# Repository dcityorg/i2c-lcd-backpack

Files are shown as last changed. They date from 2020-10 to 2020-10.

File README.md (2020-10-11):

#### I²C LCD Backpack Board for character LCD modules

<div style="text-align: center;">
<div style="display: inline-block; margin-right: 5px;">
<a href="https://www.dcity.org/dcity/wp-content/uploads/i2c-lcd-with-blackboard.jpg"><img src="https://www.dcity.org/dcity/wp-content/uploads/i2c-lcd-with-blackboard-600x400.jpg" alt="" width="300" height=“200" class="alignnone size-medium wp-image-517" /></a>
</div>
<div style="display: inline-block; margin-right: 5px;">

</div>
<div style="display: inline-block; margin-right: 5px;">
<a href="https://www.dcity.org/dcity/wp-content/uploads/i2c-lcd.jpg"><img src="https://www.dcity.org/dcity/wp-content/uploads/i2c-lcd-600x400.jpg" alt="" width="300" height=“200" class="alignnone size-medium wp-image-517" /></a>
</div>
</div>

**[This link has details](https://www.dcity.org/portfolio/i2c-lcd-backpack-board/) including**
* parts lists
* assembly instructions
* jumper configuration
* Arduino, Particle and Raspberry Pi software library usage
* Bare PC boards are available from OSHPark.

**License Information**
Open Source Hardware Design. Our License Information is [here](https://www.dcity.org/license-information/).

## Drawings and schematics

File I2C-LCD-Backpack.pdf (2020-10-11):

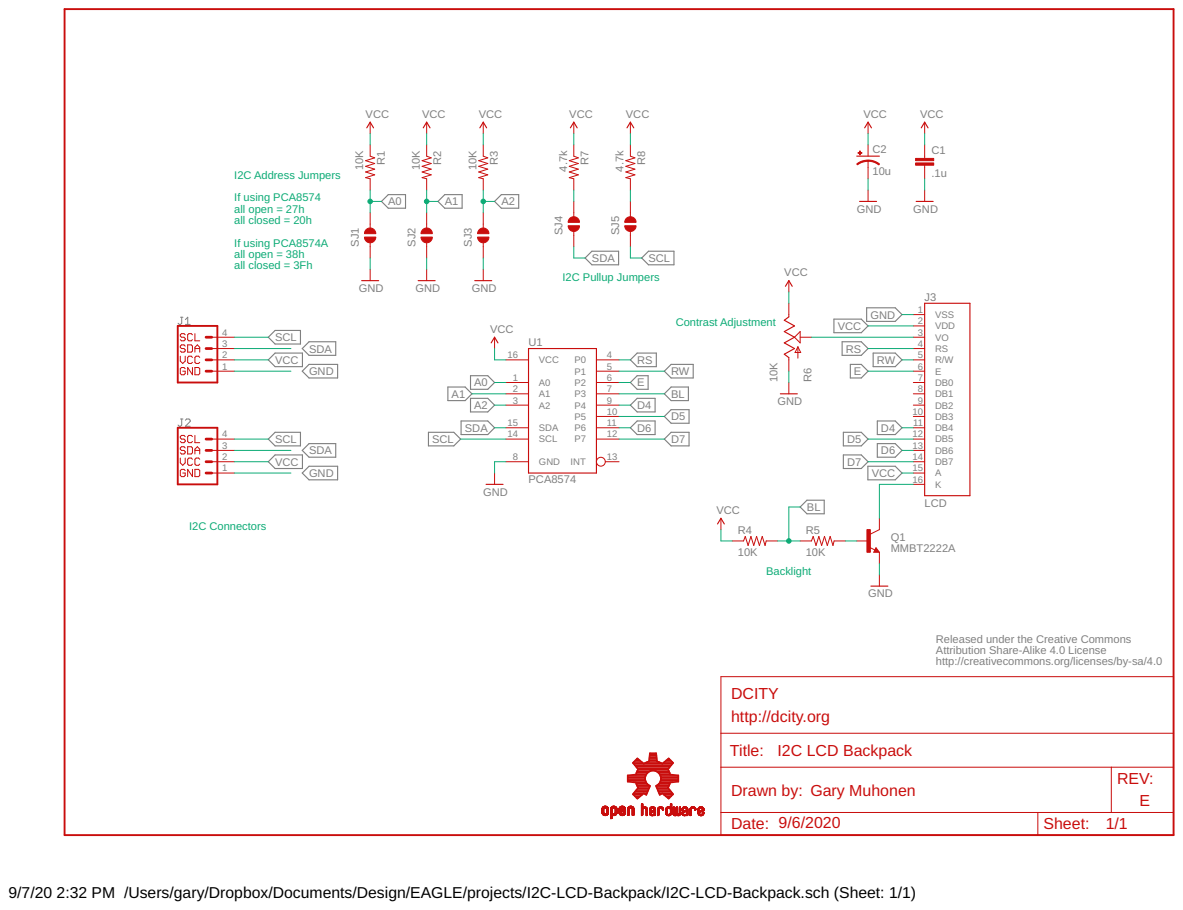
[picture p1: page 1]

I2C Address Jumpers
If using PCA8574
all open = 27h
all closed = 20h
If using PCA8574A
all open = 38h
I2C Pullup Jumpers all closed = 3Fh

Released under the Creative Commons http://creativecommons.org/licenses/by-sa/4.0
Attribution Share-Alike 4.0 License

Drawn by: | REV: E Gary Muhonen

Date: 9/6/2020 | Sheet: 1/1

9/7/20 2:32 PM /Users/gary/Dropbox/Documents/Design/EAGLE/projects/I2C-LCD-Backpack/I2C-LCD-Backpack.sch (Sheet: 1/1)

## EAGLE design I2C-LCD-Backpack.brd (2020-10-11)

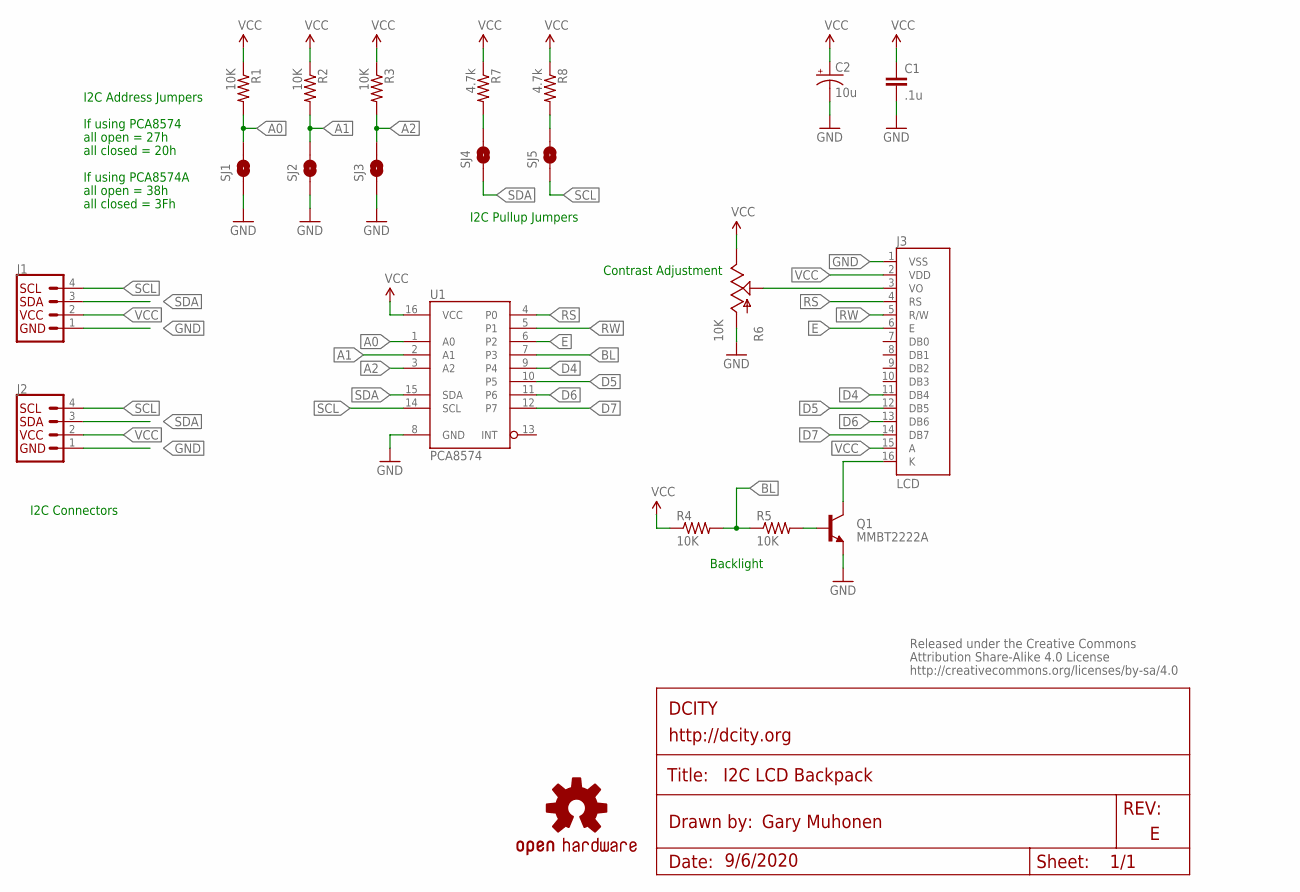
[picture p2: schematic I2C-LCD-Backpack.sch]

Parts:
C1: .1u; 0805-CAP
C2: 10u; 0805-POL
J1, J2: QWIIC_RIGHT_ANGLE; JST04_1MM_RA
J3: LCD; 1X16_LOCK
LOGO1: OSHW-LOGOS; OSHW-LOGO-S
Q1: MMBT2222A; SOT23-3
R1, R2, R3, R4, R5: 10K; 0805-RES
R6: 10K; TC33X
R7, R8: 4.7k; 0805-RES
SJ1, SJ2, SJ3, SJ4, SJ5: SOLDERJUMPERNC; SJ_2S
U1: PCA8574; TSSOP16
U$2: CREATIVE_COMMONS

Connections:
A0: R1.2, SJ1.2, U1.1 (A0)
A1: R2.2, SJ2.2, U1.2 (A1)
A2: R3.2, SJ3.2, U1.3 (A2)
BL: R4.2, R5.1, U1.7 (P3)
D4: J3.11 (DB4), U1.9 (P4)
D5: J3.12 (DB5), U1.10 (P5)
D6: J3.13 (DB6), U1.11 (P6)
D7: J3.14 (DB7), U1.12 (P7)
E: J3.6 (E), U1.6 (P2)
GND: C1.2, C2.-, J1.1, J2.1, J3.1 (VSS), Q1.2 (E), R6.1 (A), SJ1.1, SJ2.1, SJ3.1, U1.8 (GND)
unnamed: R7.2, SJ4.2
unnamed: R8.2, SJ5.2
unnamed: Q1.1 (B), R5.2
unnamed: J3.16 (K), Q1.3 (C)
unnamed: J3.3 (VO), R6.2 (S)
RS: J3.4 (RS), U1.4 (P0)
RW: J3.5 (R/W), U1.5 (P1)
SCL: J1.4, J2.4, SJ5.1, U1.14 (SCL)
SDA: J1.3, J2.3, SJ4.1, U1.15 (SDA)
VCC: C1.1, C2.+, J1.2, J2.2, J3.2 (VDD), J3.15 (A), R1.1, R2.1, R3.1, R4.1, R6.3 (E), R7.1, R8.1, U1.16 (VCC)

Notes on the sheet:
If using PCA8574
all open = 27h
all closed = 20h
I2C Connectors
Contrast Adjustment
Backlight
I2C Pullup Jumpers
all closed = 3Fh
all open = 38h
I2C Address Jumpers
If using PCA8574A

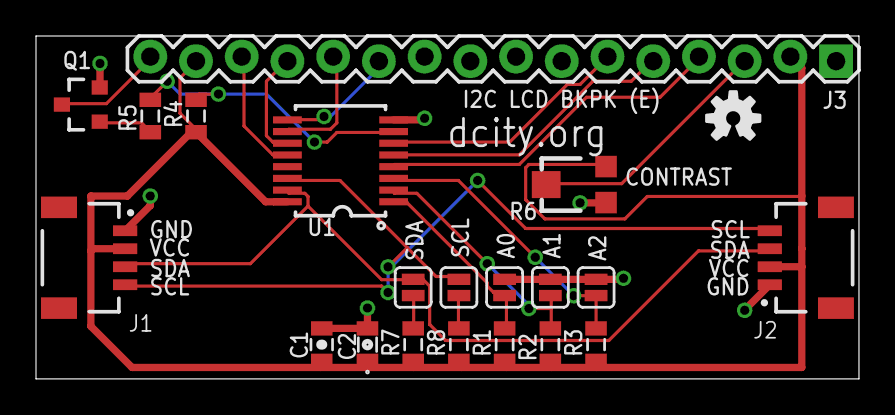
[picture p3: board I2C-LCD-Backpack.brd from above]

Board: 2 copper layers, 45.7 x 19.1 mm, 22 parts (0 on the bottom side), 20 nets.

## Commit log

2016-04-05 First commit - Rev C
    [I2C-LCD-Backpack.brd, I2C-LCD-Backpack.sch]
2018-09-14 Rev D
    [I2C-LCD-Backpack.brd, I2C-LCD-Backpack.sch]
2020-10-11 Rev E
    [I2C-LCD-Backpack.brd, I2C-LCD-Backpack.sch]
